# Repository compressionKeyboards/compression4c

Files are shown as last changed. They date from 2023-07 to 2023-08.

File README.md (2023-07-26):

# compression (4c)
PCB, ergogen, kicad files for 4c wireless split ergo keyboard

picture of 4c

This repo contains the files to order a custom PCB for chocBoard, checkout the [zmk layout](https://github.com/compressionKeyboards/4c-zmk-layout) to build firmware!

Read more about chocBoard on [compression](https://compressionkeyboards.com).

## Downloads
feel free to dig around in my working files in the repo :) but if you just want to order a PCB or print a case, checkout the releases tab.

## TODO
Fusion and STEP files will be added soon, I'm just cleaning them up a bit. Also, display cover files are not final, and just a few dimensions will be tweaked in an upcoming release.

## LICENSE
This repo is attached with Attribution-NonCommercial-ShareAlike 4.0 International Creative Commons License, learn what his means [here](https://creativecommons.org/licenses/by-nc-sa/4.0/).

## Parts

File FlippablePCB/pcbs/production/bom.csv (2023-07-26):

Designator | Footprint | Quantity | Value | LCSC Part #
_24, _23, _22, _21, _20, _19, _18, _17, _16, _15, _14, _13, _12, _11, _10, _9, _8, _7, _6, _5, _4, _3, _2, |  | 24
D1, D10, D11, D12, D13, D14, D15, D16, D17, D18, D19, D2, D20, D21, D22, D23, D24, D25, D26, D27, D28, D29, D3, D4, D5, D6, D7, D8, D9 | ComboDiode | 29
MCU1 | ProMicro | 1
OLED1 | OLED_headers | 1 | OLED
PAD1, PAD2 | SMDPad | 2
S1, S10, S11, S12, S13, S14, S15, S16, S17, S18, S19, S2, S20, S21, S22, S23, S24, S25, S26, S27, S28, S29, S3, S4, S5, S6, S7, S8, S9 | PG1350 | 29
T1, T2 | SPDT_C128955 | 2

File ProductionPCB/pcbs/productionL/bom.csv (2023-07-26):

Designator | Footprint | Quantity | Value | LCSC Part #
D1, D10, D11, D12, D13, D14, D15, D16, D17, D18, D19, D2, D20, D21, D22, D23, D24, D25, D26, D27, D28, D29, D3, D4, D5, D6, D7, D8, D9 | ComboDiode | 29 |  | C109203
JST1 | JST_PH_S2B-PH-K_02x2.00mm_Angled | 1 |  | C157932
MCU1 | ProMicro | 0
OLED1 | OLED_headers | 1 | OLED | C2889987
Panasonic_EVQPUL_EVQPUC | Panasonic_EVQPUL_EVQPUC | 1 | Panasonic_EVQPUL_EVQPUC | C79174
S1, S10, S11, S12, S13, S14, S15, S16, S17, S18, S19, S2, S20, S21, S22, S23, S24, S25, S26, S27, S28, S29, S3, S4, S5, S6, S7, S8, S9 | PG1350 | 0
T1 | SPDT_C128955 | 1 |  | C128955

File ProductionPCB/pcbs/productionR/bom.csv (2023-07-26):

Designator | Footprint | Quantity | Value | LCSC Part #
D31, D34, D36, D37, D41, D49, D51, D52, D53, D54, D57, D58, D59, D61, D62, D64, D67, D68, D69, D71, D72, D73, D74, D75, D76, D77, D79, D84, D85 | ComboDiode | 29 |  | C109203
JST1 | JST_PH_S2B-PH-K_02x2.00mm_Angled | 1 |  | C157932
MCU1 | ProMicro | 0
OLED1 | OLED_headers | 1 | OLED | C2889987
Panasonic_EVQPUL_EVQPUC | Panasonic_EVQPUL_EVQPUC | 1 | Panasonic_EVQPUL_EVQPUC | C79174
S30, S31, S32, S33, S34, S35, S36, S37, S38, S39, S40, S41, S42, S43, S44, S45, S46, S47, S48, S49, S50, S51, S52, S53, S54, S55, S56, S57, S58, S59, S60, S61, S62, S63, S64, S65, S66, S67, S68, S69, S70, S71, S72, S73, S74, S75, S76, S77, S78, S79, S80, S81, S82, S83, S84, S85, S86, S87 | PG1350 | 0
T1 | SPDT_C128955 | 1 |  | C128955

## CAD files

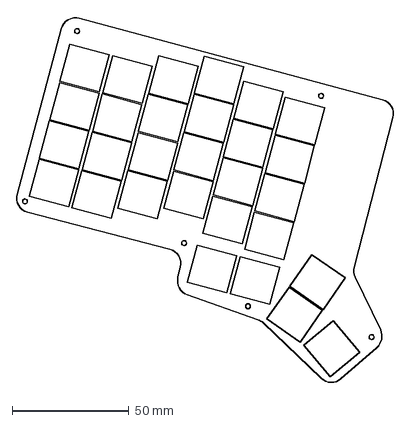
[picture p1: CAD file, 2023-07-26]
FlippablePCB/outlines/preview.dxf
162.3 x 157.5 mm

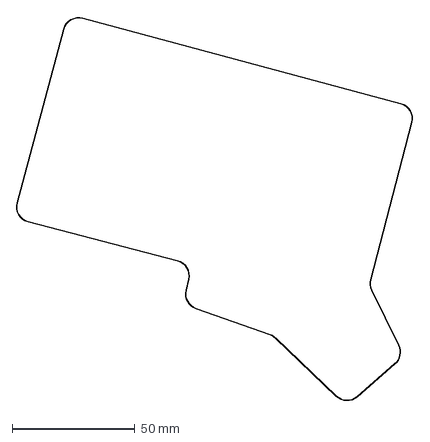
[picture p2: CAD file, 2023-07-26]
ProductionPCB/outlines/patch_outer.dxf
162.3 x 157.5 mm

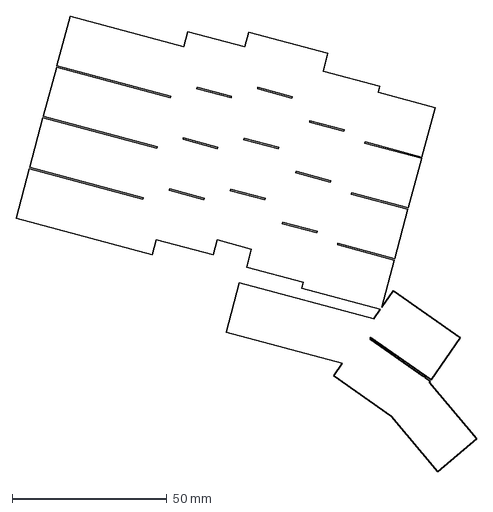
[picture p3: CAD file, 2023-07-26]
FlippablePCB/outlines/keycap_outlines15.dxf
148.8 x 147.1 mm

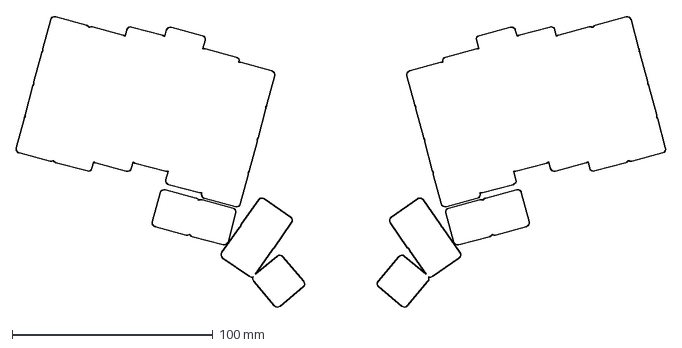
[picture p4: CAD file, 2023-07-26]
ProductionPCB/outlines/raw.dxf
323.6 x 145.0 mm

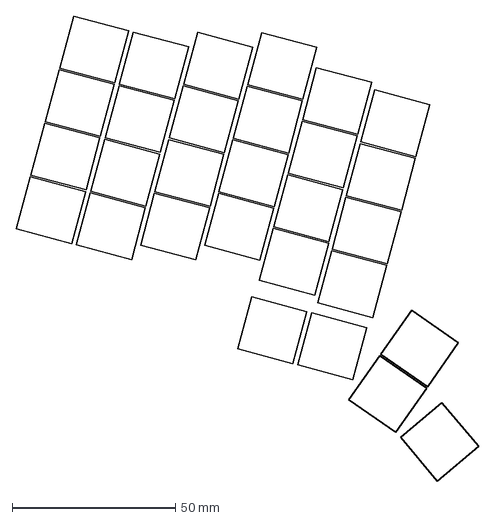
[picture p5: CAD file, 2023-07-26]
FlippablePCB/outlines/keycap_outlines.dxf
141.6 x 142.5 mm

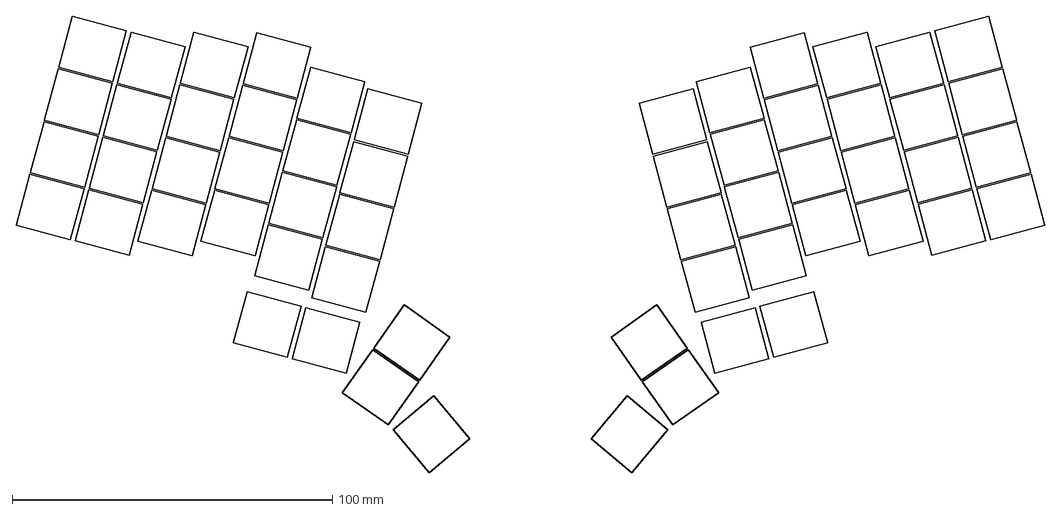
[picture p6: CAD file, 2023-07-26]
ProductionPCB/outlines/keycap_outlines.dxf
321.2 x 142.5 mm

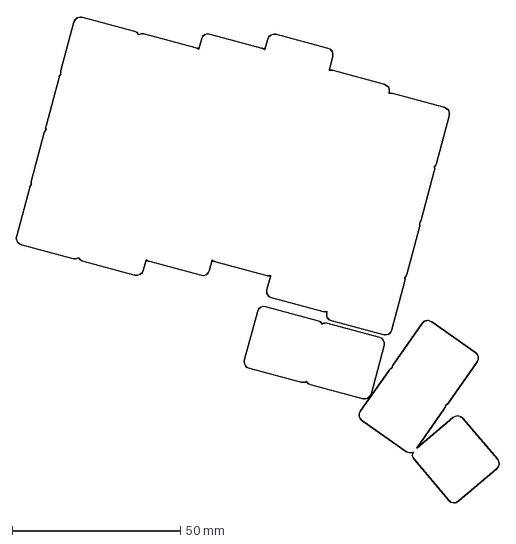
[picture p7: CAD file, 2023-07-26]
FlippablePCB/outlines/raw.dxf
143.9 x 145.0 mm

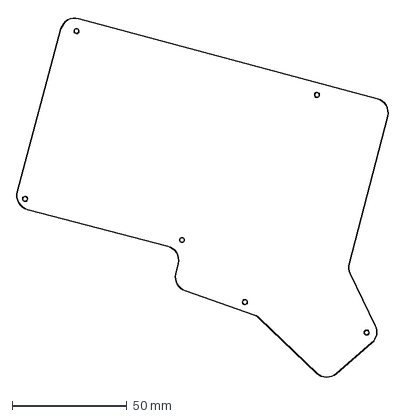
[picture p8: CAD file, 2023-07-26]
FlippablePCB/outlines/pcb.dxf
162.3 x 157.5 mm

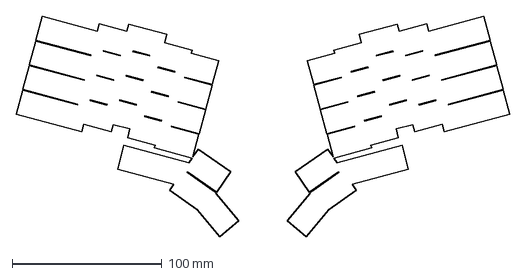
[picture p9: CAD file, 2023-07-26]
ProductionPCB/outlines/keycap_outlines15.dxf
329.9 x 147.1 mm

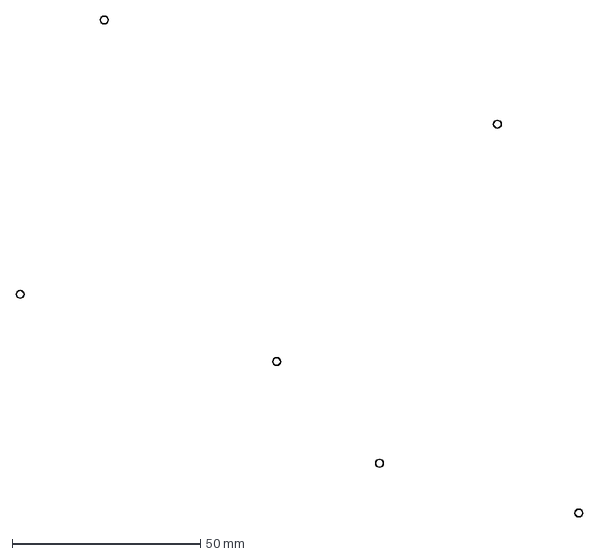
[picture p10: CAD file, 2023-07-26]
ProductionPCB/outlines/screw_holes.dxf
150.6 x 133.2 mm

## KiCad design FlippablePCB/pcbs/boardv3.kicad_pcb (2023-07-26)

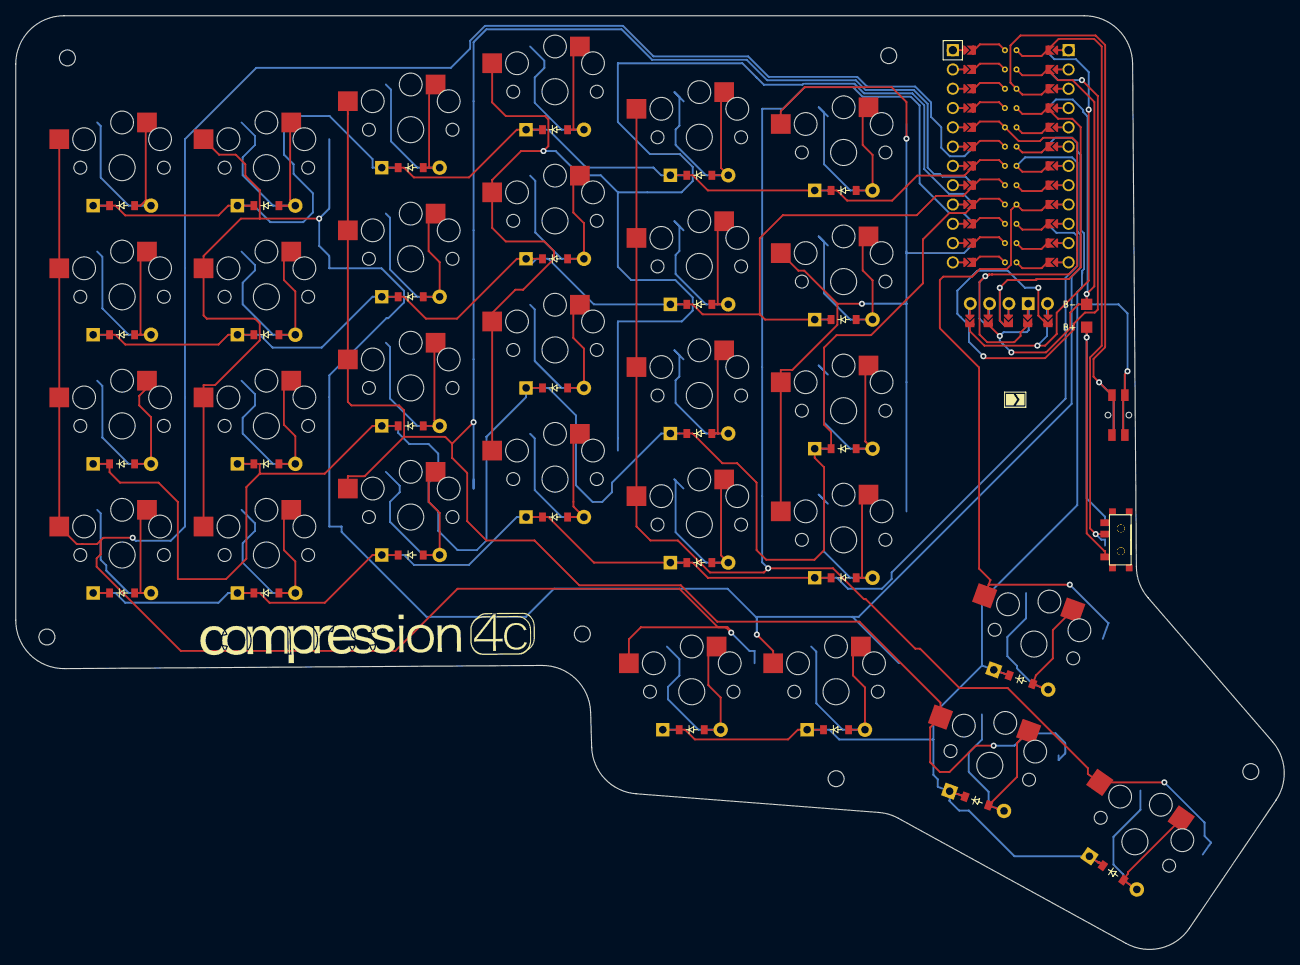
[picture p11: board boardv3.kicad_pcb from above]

Board: 2 copper layers, 167.0 x 122.9 mm, 64 parts (0 on the bottom side), 43 nets.

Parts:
D1, D2, D3, D4, D5, D6, D7, D8, D9, D10, D11, D12, D13, D14, D15, D16, D17, D18, D19, D20, D21, D22, D23, D24, D25, D26, D27, D28, D29: ComboDiode
MCU1: ProMicro
OLED1: OLED; OLED_headers
PAD1, PAD2: SMDPad
S1, S2, S3, S4, S5, S6, S7, S8, S9, S10, S11, S12, S13, S14, S15, S16, S17, S18, S19, S20, S21, S22, S23, S24, S25, S26, S27, S28, S29: PG1350
T1, T2: SPDT_C128955

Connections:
Bplus: PAD1.1, T1.1, T2.1
GND: MCU1.2, MCU1.21, MCU1.22, PAD2.1
P3: D25.1, D26.1, D27.1, D28.1, D29.1, MCU1.19
P4: D4.1, D8.1, D12.1, D16.1, D20.1, D24.1, MCU1.18
P5: D3.1, D7.1, D11.1, D15.1, D19.1, D23.1, MCU1.17
P6: D2.1, D6.1, D10.1, D14.1, D18.1, D22.1, MCU1.16
P7: D1.1, D5.1, D9.1, D13.1, D17.1, D21.1, MCU1.15
P14: MCU1.10, S17.2, S18.2, S19.2, S20.2, S29.2
P15: MCU1.9, S13.2, S14.2, S15.2, S16.2, S28.2
P16: MCU1.11, S21.2, S22.2, S23.2, S24.2
P18: MCU1.8, S9.2, S10.2, S11.2, S12.2, S27.2
P19: MCU1.7, S5.2, S6.2, S7.2, S8.2, S26.2
P20: MCU1.6, S1.2, S2.2, S3.2, S4.2, S25.2
RAW: MCU1.1, T1.2, T2.2
far_home: D29.2, S29.1
home_home: D27.2, S27.1
home_top: D28.2, S28.1
index_bottom: D17.2, S17.1
index_home: D18.2, S18.1
index_num: D20.2, S20.1
index_top: D19.2, S19.1
inner_bottom: D21.2, S21.1
inner_home: D22.2, S22.1
inner_num: D24.2, S24.1
inner_top: D23.2, S23.1
middle_bottom: D13.2, S13.1
middle_home: D14.2, S14.1
middle_num: D16.2, S16.1
middle_top: D15.2, S15.1
near1_home: D25.2, S25.1
near2_home: D26.2, S26.1
outer_bottom: D1.2, S1.1
outer_home: D2.2, S2.1
outer_num: D4.2, S4.1
outer_top: D3.2, S3.1
pinky_bottom: D5.2, S5.1
pinky_home: D6.2, S6.1
pinky_num: D8.2, S8.1
pinky_top: D7.2, S7.1
ring_bottom: D9.2, S9.1
ring_home: D10.2, S10.1
ring_num: D12.2, S12.1
ring_top: D11.2, S11.1

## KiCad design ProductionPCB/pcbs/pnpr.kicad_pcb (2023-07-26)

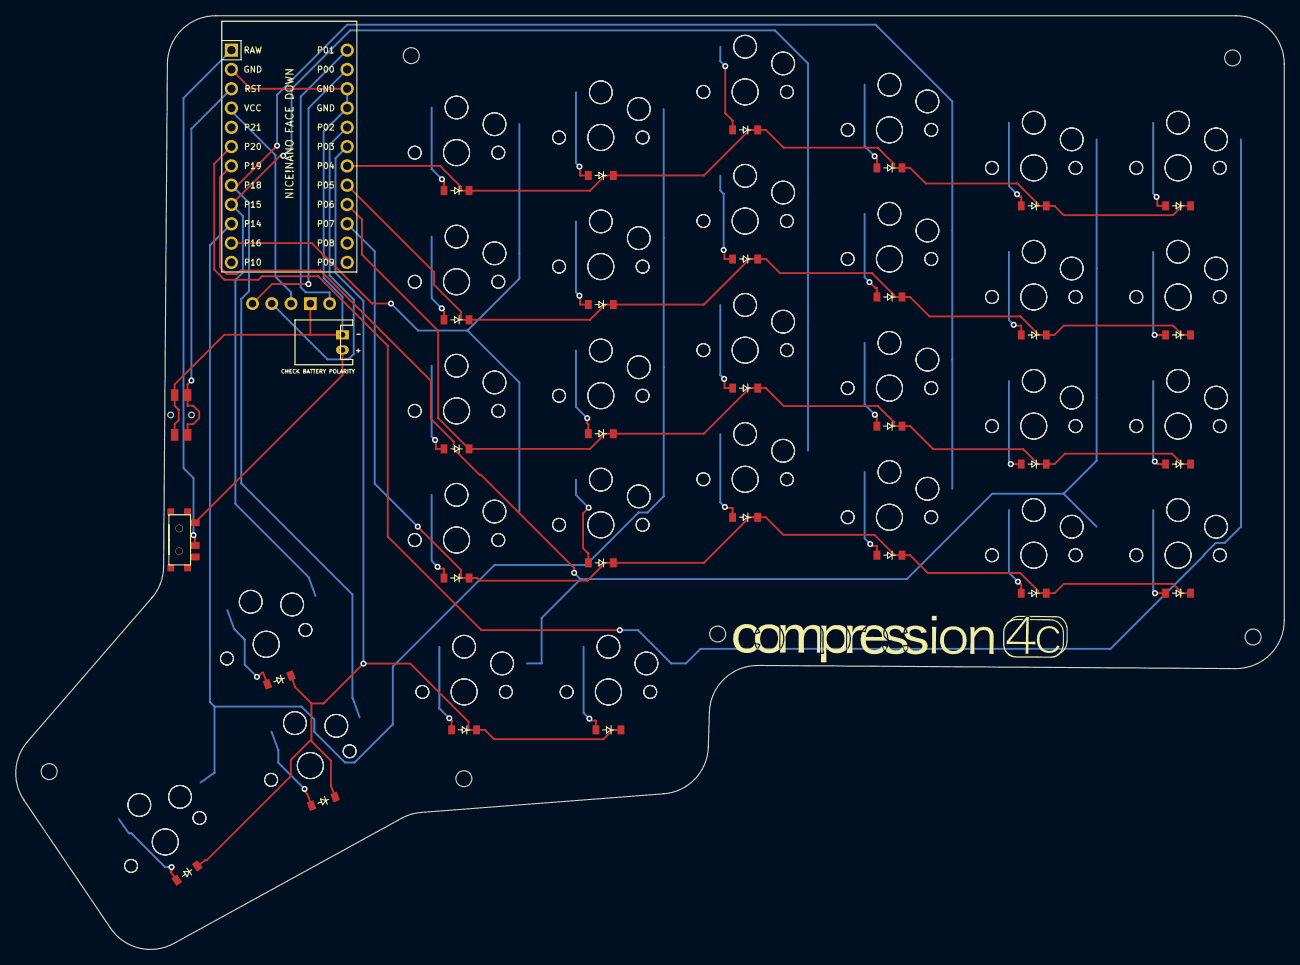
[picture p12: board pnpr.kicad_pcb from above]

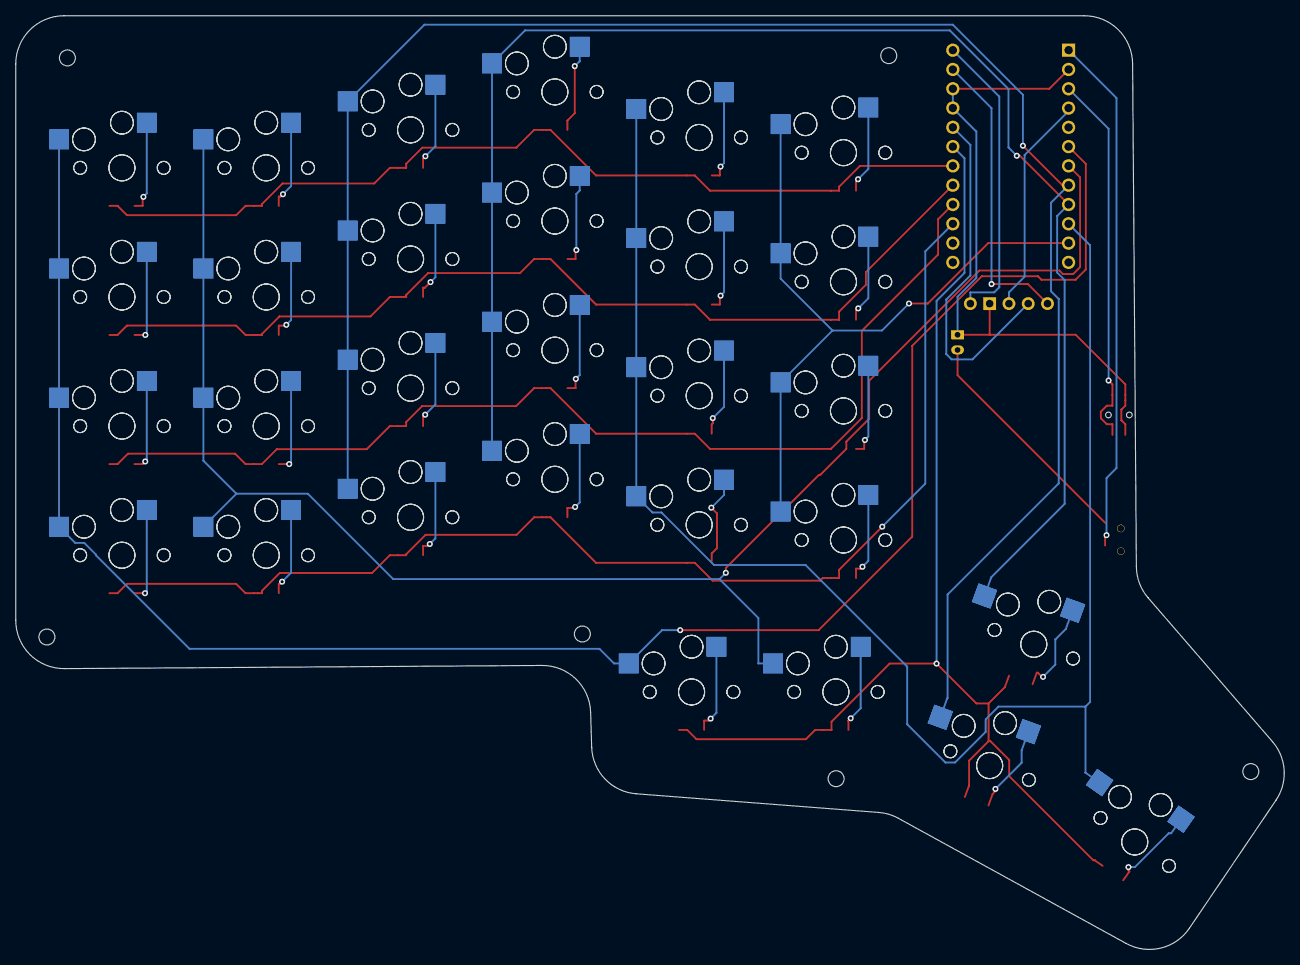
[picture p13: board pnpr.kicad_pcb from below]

Board: 2 copper layers, 167.0 x 122.9 mm, 92 parts (29 on the bottom side), 44 nets.

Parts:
D31, D34, D36, D37, D41, D49, D51, D52, D53, D54, D57, D58, D59, D61, D62, D64, D67, D68, D69, D71, D72, D73, D74, D75, D76, D77, D79, D84, D85: ComboDiode
JST1: JST_PH_S2B-PH-K_02x2.00mm_Angled
MCU1: ProMicro
OLED1: OLED; OLED_headers
Panasonic_EVQPUL_EVQPUC: Panasonic_EVQPUL_EVQPUC
S30, S31, S32, S33, S34, S35, S36, S37, S38, S39, S40, S41, S42, S43, S44, S45, S46, S47, S48, S49, S50, S51, S52, S53, S54, S55, S56, S57, S58, S59, S60, S61, S62, S63, S64, S65, S66, S67, S68, S69, S70, S71, S72, S73, S74, S75, S76, S77, S78, S79, S80, S81, S82, S83, S84, S85, S86, S87: PG1350
T1: SPDT_C128955

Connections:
Bplus: JST1.2, T1.1
GND: JST1.1, MCU1.2, MCU1.15, MCU1.16, Panasonic_EVQPUL_EVQPUC.1
P3: D54.1, D57.1, D58.1, D84.1, D85.1, MCU1.18
P4: D37.1, D41.1, D49.1, D53.1, D62.1, D74.1, MCU1.19
P5: D36.1, D52.1, D61.1, D69.1, D73.1, D77.1, MCU1.20
P6: D31.1, D51.1, D64.1, D68.1, D72.1, D76.1, MCU1.21
P7: D34.1, D59.1, D67.1, D71.1, D75.1, D79.1, MCU1.22
P14: MCU1.10, S46.2, S47.2, S48.2, S49.2, S58.2, S75.2, S76.2, S77.2, S78.2, S87.2
P15: MCU1.9, S42.2, S43.2, S44.2, S45.2, S57.2, S71.2, S72.2, S73.2, S74.2, S86.2
P16: MCU1.11, S50.2, S51.2, S52.2, S53.2, S79.2, S80.2, S81.2, S82.2
P18: MCU1.8, S38.2, S39.2, S40.2, S41.2, S56.2, S67.2, S68.2, S69.2, S70.2, S85.2
P19: MCU1.7, S34.2, S35.2, S36.2, S37.2, S55.2, S63.2, S64.2, S65.2, S66.2, S84.2
P20: MCU1.6, S30.2, S31.2, S32.2, S33.2, S54.2, S59.2, S60.2, S61.2, S62.2, S83.2
RAW: MCU1.1, T1.2
RST: MCU1.3, Panasonic_EVQPUL_EVQPUC.2
mirror_far_home: D58.2, S58.1, S87.1
mirror_home_home: D85.2, S56.1, S85.1
mirror_home_top: D57.2, S57.1, S86.1
mirror_index_bottom: D75.2, S46.1, S75.1
mirror_index_home: D76.2, S47.1, S76.1
mirror_index_num: D49.2, S49.1, S78.1
mirror_index_top: D77.2, S48.1, S77.1
mirror_inner_bottom: D79.2, S50.1, S79.1
mirror_inner_home: D51.2, S51.1, S80.1
mirror_inner_num: D53.2, S53.1, S82.1
mirror_inner_top: D52.2, S52.1, S81.1
mirror_middle_bottom: D71.2, S42.1, S71.1
mirror_middle_home: D72.2, S43.1, S72.1
mirror_middle_num: D74.2, S45.1, S74.1
mirror_middle_top: D73.2, S44.1, S73.1
mirror_near1_home: D54.2, S54.1, S83.1
mirror_near2_home: D84.2, S55.1, S84.1
mirror_outer_bottom: D59.2, S30.1, S59.1
mirror_outer_home: D31.2, S31.1, S60.1
mirror_outer_num: D62.2, S33.1, S62.1
mirror_outer_top: D61.2, S32.1, S61.1
mirror_pinky_bottom: D34.2, S34.1, S63.1
mirror_pinky_home: D64.2, S35.1, S64.1
mirror_pinky_num: D37.2, S37.1, S66.1
mirror_pinky_top: D36.2, S36.1, S65.1
mirror_ring_bottom: D67.2, S38.1, S67.1
mirror_ring_home: D68.2, S39.1, S68.1
mirror_ring_num: D41.2, S41.1, S70.1
mirror_ring_top: D69.2, S40.1, S69.1

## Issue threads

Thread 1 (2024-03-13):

f3d model

DaniilMaximov, 2024-03-13:
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

Hi, you have succeeded in creating a very cool keyboard! I use it every day at the moment.
But I'm also using a special magnetic connector and because of that I won't be able to use the travel case. Would you be able to send me the source files in f3d or step format? I also want to modify the keyboard body a bit.
I would be very grateful!

bennetthermanoff, 2024-03-19:
Absolutely. Shoot me a message on the discord: https://discord.gg/MjRrj3Cn

bennetthermanoff, 2024-03-19:
[Case.zip](https://github.com/compressionKeyboards/compression4c/files/14651487/Case.zip)

bennetthermanoff, 2024-03-19:
Looks like an amazing build! Love the wired version.

DaniilMaximov, 2024-03-19:
Thank u so much!

RichardFevrier, 2024-05-28:
Hi 👋 was it necessary to modify the pcb to be non wireless?

DaniilMaximov, 2024-05-29:
Hi! Yes, but unfortunately I can't find changed files for wierd pcb quickly

RichardFevrier, 2024-05-29:
I'll be patient 🙂 Thanks already for answering.

The Compression 4c is so great with the case @bennetthermanoff and to my eyes this makes it even better @DaniilMaximov
Thanks both for your work! 🙏❤️

Now probably stupid questions but:
- using the cabled version removes completely the wireless functionality?
- can the power/data cable be swapped either side or flashing the firmware will be requiered for that matter?

DaniilMaximov, 2024-05-29:
1. yes - controllers are different. I use Atmega 32U4
2. yes, but u have to change it in firmware

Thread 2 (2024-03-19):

3D files for generic version generator

BlueDrink9, 2024-03-19:
I love this design. It'd be a shame to confine it to a single board. I'm interested in creating a generator for cases like this. I'm thinking openscad, input an existing stl or maybe even pcb file, and have openscad project the outline then build the case from there. Can't say I'd do it soon, but definitely at some point. I'd be very happy to suggest all donations get forwarded to you. Would you be willing to share the 3D design files, step, or even just dimensions etc to help me create a parametrised port of this?

bennetthermanoff, 2024-03-19:
Absolutely! shoot me a message on the discord I can get you f3d and step files. https://discord.gg/MjRrj3Cn

bennetthermanoff, 2024-03-19:
Also no need for donos. A link to this github would be enough :)

Closed 2024-03-19.

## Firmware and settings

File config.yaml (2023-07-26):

#https://github.com/tsteffek/Ergogen-V4-Migration-Guide
units:
  kx: cx
  ky: cy
  px: 2
  py: 2
points:
  key:
    padding: cy
    tags:
      1u: true
    
          
  zones:
    matrix:
      anchor:
        rotate: 5
      columns:
        outer:
            key:
              column_net: P20
        pinky:
          key:
            column_net: P19
        ring:
          key:
            stagger: 5
            column_net: P18
        middle:
          key:
            stagger: 5
            column_net: P15
        index:
          key:
            stagger: -6
            column_net: P14
        inner:
          key:
            stagger: -2
            column_net: P16
      rows:
        bottom:
          row_net: P7
        home:
          row_net: P6
        top:
          row_net: P5
        num:
          row_net: P4
    thumbfan:
      anchor:
        ref: matrix_inner_bottom
        shift: [-20, -20]
      columns:
        near1:
          key:
            column_net: P20
        near2:
          key:
            column_net: P19
        home:
          rows:
            home:
              column_net: P18
            top:
              column_net: P15
              row_net: P3
          key:
            spread: 21.25
            splay: -20
            origin: [-28, -2]
        far:
          key:
            column_net: P14
            spread: 21.25
            splay: -15
            origin: [-11, -2]
      rows:
        home:
          row_net: P3
      
  rotate: -20
outlines:
    raw: 
      - what: rectangle
        #side: left
        size: [kx + px, ky + py]
        corner: px
        where: true
        
        
    patch_outer:
      - what: polygon
        fillet: 6.35
        points:
          - ref: matrix_outer_num
            shift: [-14,20]
          - ref: matrix_outer_num
            shift: [133,20]
          - ref: thumbfan_home_top
            shift: [10,12]
          - ref: thumbfan_far_home
            shift: [12,20]
          - ref: thumbfan_far_home
            shift: [12.5,-11]
          - ref: thumbfan_near2_home
            shift: [7,-16]
          - ref: thumbfan_near1_home
            shift: [-13,-13]
          - ref: thumbfan_near1_home
            shift: [-13.5,3.5]
          - ref: matrix_outer_bottom
            shift: [-14,-15]

    screw_holes:
      - what: circle
        adjust:
            ref: matrix_outer_num
            shift: [-0.4 cx, .85 cy]
        radius: 1.05
      - what: circle
        adjust:
            ref: matrix_inner_num
            shift: [.33 cx, 0.75 cy]
        radius: 1.05
      - what: circle
        adjust:
            ref: matrix_outer_bottom
            shift: [-.55 cx, -.635 cy]
        radius: 1.05
      - what: circle
        adjust:
            ref: matrix_inner_bottom
            shift: [-.055 cx, -1.85 cy]
        radius: 1.05
      - what: circle
        adjust:
            ref: matrix_middle_bottom
            shift: [.2 cx, -1.2 cy]
        radius: 1.05
      - what: circle
        adjust:
            ref: thumbfan_far_home
            shift: [.4 cx, .96 cy]
        radius: 1.05
      
        
    
        
    keycap_outlines:
      - what: rectangle
        #side: left
        size: [1cx - 0.5, 1cy - 0.5] # Choc keycaps are 17.5 x 16.5
        bound: false    
        #tags: [1u]       
        where: true
    keycap_outlines15:
      - what: rectangle
        #side: left
        size: [1.5cx - 0.5, 1cy - 0.5] # Choc keycaps are 17.5 x 16.5
        bound: false    
        #tags: [15u]     
        where: true  
    preview:
        main:
          what: outline
          name: patch_outer
        switches:
          what: outline
          name: keycap_outlines
          operation: subtract
        holes:
          what: outline
          name: screw_holes
          operation: subtract
    pcb:
        main:
          what: outline
          name: patch_outer
        holes:
          what: outline
          name: screw_holes
          operation: subtract
pcbs:
  top_plate:
    outlines:
      edge:
        outline: preview 
        layer: Edge.Cuts
  board:
    outlines:
      edge:
        outline: pcb
        layer: Edge.Cuts
    footprints:
      choc_hotswap:
        what: choc
        where: true
        params:
          keycaps: true
          reverse: true
          hotswap: true
          from: "{{colrow}}"
          to: "{{column_net}}"
      diode:
        what: diode
        where: true
        params:
          from: "{{colrow}}"
          to: "{{row_net}}"
        adjust:
          shift: [0, -5]
      mcu_l:
        what: promicro_pretty
        params:
          orientation: up
        adjust:
          ref:
            - matrix_inner_top
          shift: [22, -9+1.5*cy]
          rotate: 270
      oled_l:
        what: oled
        adjust:
          ref:
            - matrix_inner_top
          shift: [14.5, -30+1.5 cy]
          rotate: 90
        params:
          CS: P1
          SCL: P2
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
